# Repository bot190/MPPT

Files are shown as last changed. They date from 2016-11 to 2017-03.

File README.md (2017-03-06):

# MPPT
Maximum Power Point Tracker (MPPT)

Oh look an MQP.

Software: Use CCS: [Download TI CCS](https://www.ti.com/licreg/docs/swlicexportcontrol.tsp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) or on Hutt, or any lab computer.

This is a copy of the git repository used during the course of the project.  Contents are organized by folder and should be fairly self-explanatory.  

Board_Design contains all of the schematics and layout diagrams used for the design of the PCB. These will require NI Multisim 13 and/or NI Ultiboard 13 or later to open.

MATLAB contains matlab code used for the project, mostly for the simulation of software algorithms.  MATLAB 2015b or later should be sufficient.

PSpice contains the SPICE simulations of the circuits. These simulations were run with OrCad PSpice, but can in theory run in any SPICE netlist simulator.

Software is a TI Code Composer Studio workspace.  It includes the "Sweep" algorithm, the "Perturb and Observe" algorithm, and the "Beta" algorithm.

Any Python code was made in Python 3.

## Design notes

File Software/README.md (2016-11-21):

# Timer A0 Interrupt (4KHz)
    Configure ADC for first input
    Start ADC
    
# ADC Interrupt
    IF (Vout){
    	Add measurement to sample array
        Config ADC for V-MPPT
		Start ADC
        Enable flag to Adjust Dout
    } else if (V-MPPT) {
    	Add measurement to sample array
    	Config ADC for I-MPPT
       	Start ADC
    } else if (I-MPPT) {
    	Add measurement to sample array
       	Enable flag to Run MPPT Algorithm
       	Increment sample counter
       		Roll over at Sample Size
    }
    
If MPPT Buck doesn't see voltage when duty cycle is increased, then probably no input.
Shut off Output buck AND shut off MPPT buck. Periodically test this, turning
MPPT buck on, and leaving out buck off 
    
# Dout Adjust
    // Monitor Vout and adjust Dout as necessary
    Calulate error (setpoint - value)
    Integrate error (integrator += Ki * error)

# MPPT Algorithms

## Sweep
1. Start at 0% Duty Cycle - Ramp to 100% Duty cycle
 Calculate Power at each point update max_power_duty_cycle
2. After entire range is swept, go to max_pwer_duty_cycle

## Peturb and Observe
1. Adjust duty cycle based on perturb_dir
 Set prev_power to current_power
 Calculate current_power from current & voltage readings
2. If current_power < prev_power, reverse perturb_dir
3. Repeat forever

## Beta Method
1. Measure Voltage & Current, calculate B = ln (i/v) - C * v
2. If B is within Bmin & Bmax
 Switch to Perturb & Observe
3. Else adjust duty cycle based on B
 (Duty Cycle = D-Old + K * Bg-B)

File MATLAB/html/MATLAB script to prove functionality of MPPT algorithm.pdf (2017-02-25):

## MATLAB script to prove functionality of MPPT algorithm

Authors: Andrew Flynn, Ben Beauregard, Johnathan Adams

This script attempts to imulate the functionality of the maximum power point tracking algorithm built in C for use with the projects hardware. This is meant as a proof that the concept is sound and the algorithm will track theoretical and actual maximum power point data, not as an actual implementation to run on the hardware. As such, certain things are abstracted, such as duty cycle setting and tracking, ISRs, and other MCU-specific functionality.

Contents

Flynn's Code to load Experimental Data
Data-Error Check
Ben's MPPT Algorithm
Graph data

Flynn's Code to load Experimental Data

We're just calling another script here. It reads a data file in a terribly... unintuitive way, but it does work, and if it ain't broke...

clear;
fid = fopen('SolarSweepData.txt', 'r') ; % Open source file.
if fid == ‐1
disp('ERROR 404: File Not Found') ;
else
fgetl(fid) ; | % Read/discard line.
fgetl(fid) ; | % Read/discard line.
buffer = fread(fid, Inf) ; | % Read rest of the file.
fclose(fid);
fid = fopen('_temp.txt', 'w') ; | % Open destination file.
fwrite(fid, buffer) ; | % Save to file.
fclose(fid) ;
A = tdfread('_temp.txt') ;
delete('_temp.txt') ;
end

Data-Error Check

If we have more voltage samples than current samples something is wrong and should probably be fixed before the simulation is continued.

if length(A.Voltage_0x5BV0x5D) ~= length(A.x0x23_Current_0x5BA0x5D)
disp('Sample Size Mismatch. What are you doing?')
else
IV = [A.Voltage_0x5BV0x5D.'; A.x0x23_Current_0x5BA0x5D.'];
end

Ben's MPPT Algorithm

The "Sweep" Algorithm runs continuously in a loop using ISR's that call eachother. This shows only one complete sweep of the data, as all subsequent sweeps of identical data will give identical results.

max_power = 0; % Holds Max Power Value
max_power_ind = 0; % Emulates Duty‐Cycle tracking
power = 0; | % Holds power value for
ind = 1; | % Array Index, emulates MCU duty cycle tracking
current_sample = 0; % Current Sample Variable for readibility voltage_sample = 0; % Voltage Sample Variable for readibility

while ind < length(IV)

% Read in samples from ADC
current_sample = IV(2,ind);
voltage_sample = IV(1,ind);
power = current_sample * voltage_sample;

% If the current sample is higher than the previous maximum power % point, save it.
if power > max_power
max_power = power;
max_power_ind = ind;
end

% Increase Duty Cycle/Index ind = ind + 1;
end

Graph data

This is a wall of nonsense that I promise you works just fine and you don't have to waste your time reading.

% Here, we display consice numerical results. The wierdness comes from
% trying to stay under 80 characters per line.
disp(['The calculated maximum power was ',num2str(max_power)]);
str = 'The maximum power point was at index ';
st = ' of ';
disp([str,num2str(max_power_ind),st,num2str(length(A.Voltage_0x5BV0x5D))]); str = 'The theoretical duty cycle is ';
st = ' percent';
disp([str,num2str(100*max_power_ind/length(A.Voltage_0x5BV0x5D)),st]);

% Too complex half‐shared axis multiple y‐scale plotting
% Mostly because of MATLAB 2015... (As opposed to 2016)
x = A.Voltage_0x5BV0x5D;
y1 = A.x0x23_Current_0x5BA0x5D;
y2 = A.Voltage_0x5BV0x5D.*A.x0x23_Current_0x5BA0x5D; [hAx,hLine1,hLine2] = plotyy(x,y1,x,y2); title('Power, Current and Voltage Characteristics') xlabel('Voltage, [V]')
ylabel(hAx(1),'Current, [A]') % left y‐axis ylabel(hAx(2),'Power, [W]') % right y‐axis hLine1.LineStyle = '‐';
hLine2.LineStyle = '‐';
hold on;
v = IV(1,max_power_ind);
plot([v v], [0 max_power],'Color',[0 1 0]); grid on;
grid minor;

The calculated maximum power was 5.3695
The maximum power point was at index 30 of 36 The theoretical duty cycle is 83.3333 percent

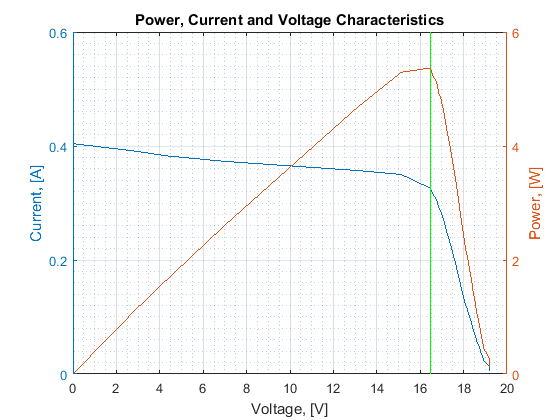
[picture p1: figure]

Published with MATLAB® R2015b (http://www.mathworks.com/products/matlab/)

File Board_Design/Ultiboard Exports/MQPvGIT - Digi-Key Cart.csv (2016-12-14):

15SQ100TR | 4
2224-H-RC | 0
2300LL-102-RC | 0
151031VS06000 | 4
1935161 | 0
ACS722LLCTR-10AU-T | 0
BZX79C3V6 | 3
DMT6009LCT | 2
ESY107M050AG3AA | 3
FB37M6K0156KC | 0
FG18C0G2A272JNT06 | 0
HDR1X2 | 4
HDR1X10 | 3
K104K10X7RF5UH5 | 2
K333K15X7RF5TH5 | 0
L78L33ABZ-AP | 0
LTI1632CN8 | 1
MIC5021YN | 1
MSP430G3553 | 2
PJ-018 | 2
RNF14FTD1K00 | 2
RNF14FTD10K0 | 2
RNF14FTD20K0 | 2
RNF14FTD75K0CT-ND | 3
RNF14FTD182R | 2
RNMF14FTC750K | 0
RSF1JT1K80 | 5

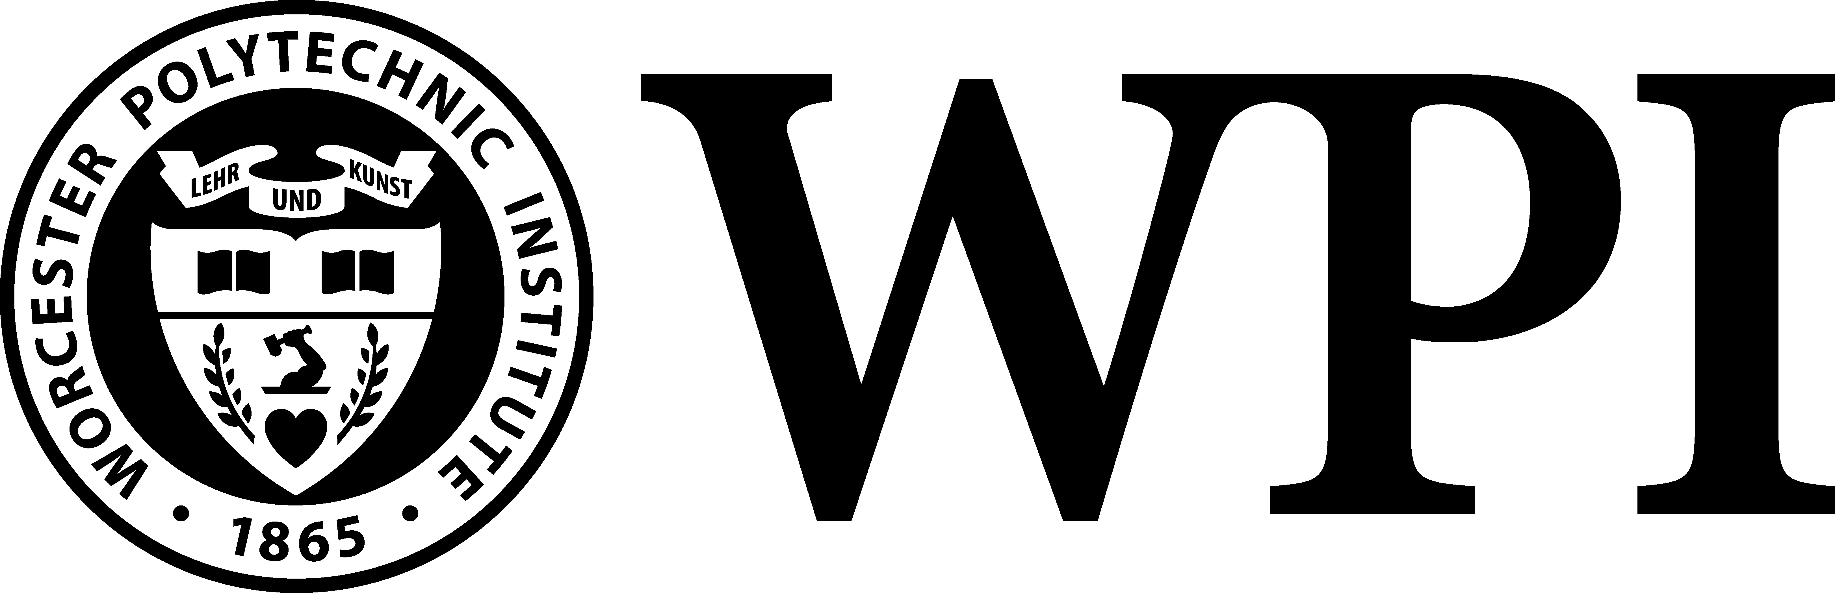
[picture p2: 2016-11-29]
Board_Design/WPI_Inst_Prim_White_Rev.bmp

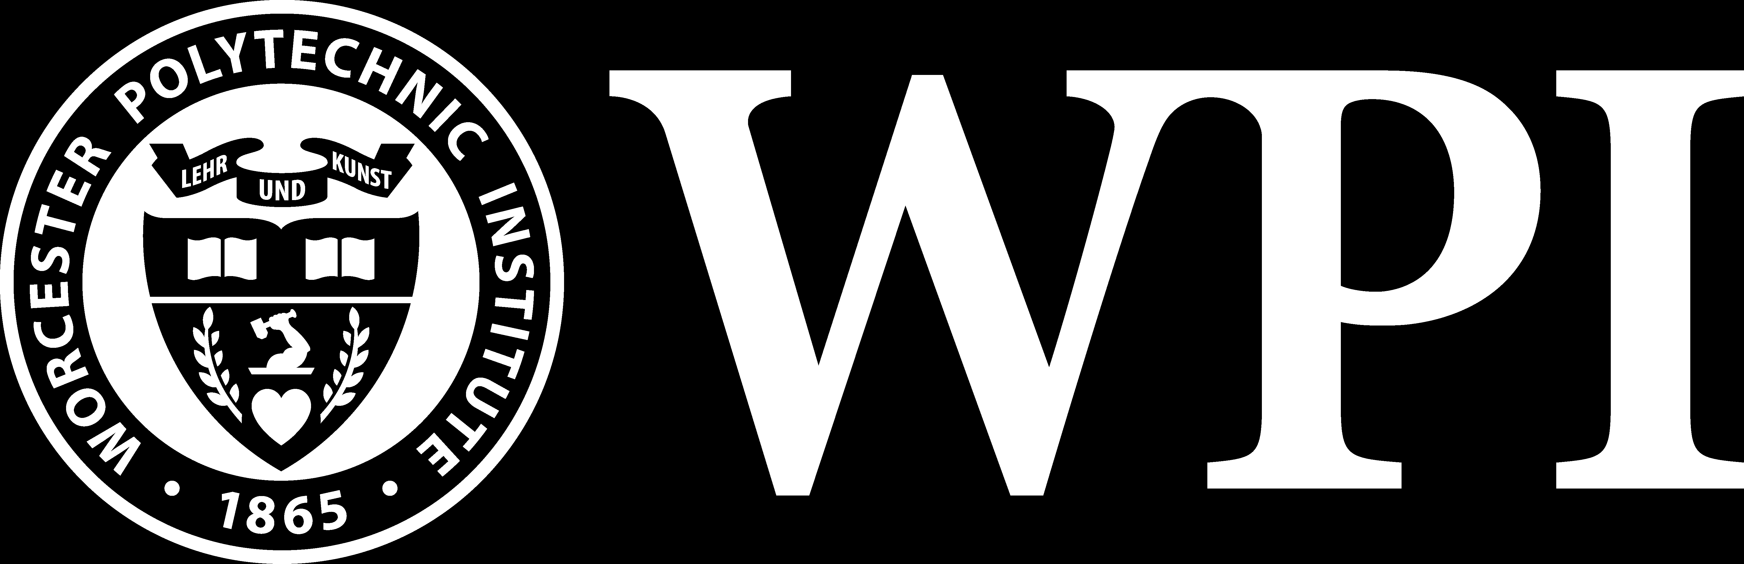
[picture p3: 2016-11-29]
Board_Design/WPI_Inst_Prim_White_Rev_Inv.bmp

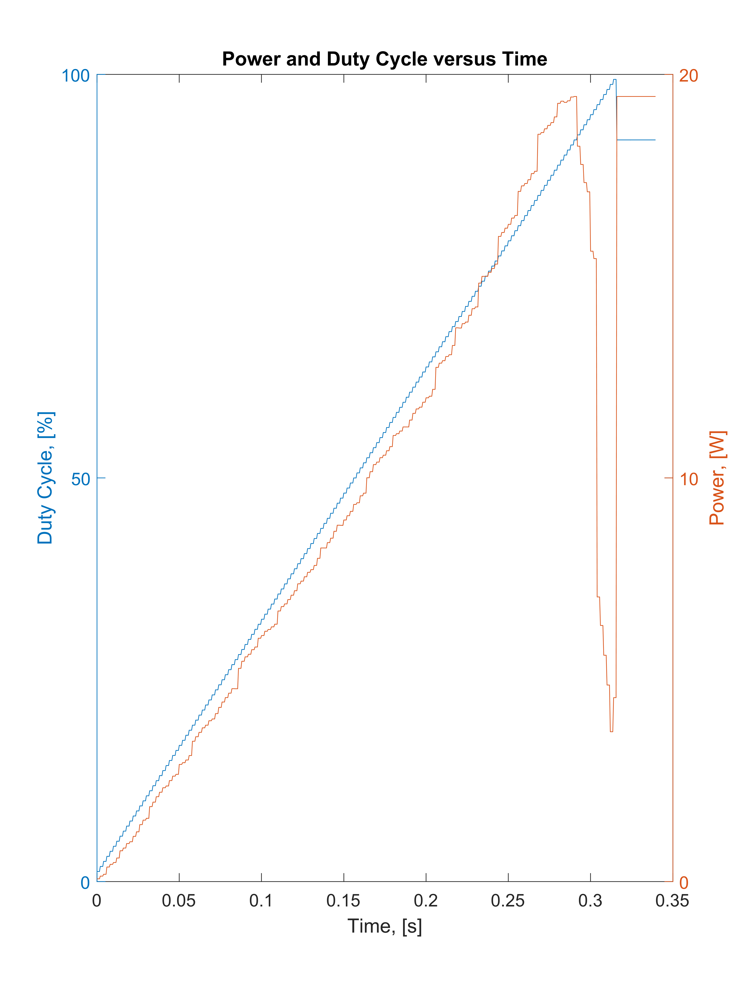
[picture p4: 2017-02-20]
MATLAB/sweep_simulation.png

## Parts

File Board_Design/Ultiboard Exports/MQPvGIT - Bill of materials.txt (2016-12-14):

Ultiboard Information Export File

Design Name  : MQPvGIT - Bill of materials
Report Date  : 8 December 2016
Report Time  : 13:30
--------------------------------------------------------------------------------

VALUE        SHAPE        #    REFDES       

15SQ100TR    R6 - SMC     4    D1,D2,D3,D4  
2224-H-RC    2224-H-RC    6    L2,L3,L4,L5,L6,L7
2300LL-102-RC 2300LL-102-RC 2    L1,L8        
151031VS06000 151031VS06000 3    LED1,LED2,LED3
1935161      1935161      3    J1,J5,J9     
ACS722LLCTR-10AU-T SOIC127P600X175-8N 1    U1           
BZX79C3V6    DO-35        2    D5,D6        
DMT6009LCT   to220        2    Q1,Q2        
ESY107M050AG3AA ESY107M050AG3AA 2    C7,C17       
FB37M6K0156KC FB37M6K0156KC 2    C1,C16       
FG18C0G2A272JNT06 FG18C0G2A272JNT06 2    C6,C12       
HDR1X2       HDR1X2       6    J2,J3,J4,J7,J8,J12
HDR1X10      HDR1X10      2    J10,J11      
K104K10X7RF5UH5 K104K10X7RF5UH5 10   C2,C3,C4,C5,C8,C9,C11,C13,C14,C18
K333K15X7RF5TH5 K104K10X7RF5UH5 2    C10,C15      
L78L33ABZ-AP TO265P419X482X935-3P 1    U3           
LT1632CN8    DIP8300      1    U6           
MIC5021YN    DIP8300      2    U2,U4        
MSP430G3553  dip20300     1    U5           
PJ-018       PJ-018       1    J6           
RNF14FTD1K00 RNF14FTD1K00 1    R1           
RNF14FTD10K0 RNF14FTD182R 1    R11          
RNF14FTD20K0 RNF14FTD182R 1    R12          
RNF14FTD75K0CT-ND RNF14FTD182R 2    R8,R10       
RNF14FTD182R RNF14FTD182R 1    R6           
RNMF14FTC750K RES1300-700X250 2    R7,R9        
RSF1JT1K80   HHV1WSJT-73-2M 4    R2,R3,R4,R5

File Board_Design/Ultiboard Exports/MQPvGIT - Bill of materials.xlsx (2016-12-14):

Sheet: MQPvGIT - Bill of materials
Ultiboard Information Export File
Design Name : MQPvGIT - Bill of materials
Report Date : 8 December 2016
Report Time : 13:30
--------------------------------------------------------------------------------
VALUE | SHAPE | # | REFDES | Have: | Need:
15SQ100TR | R6 - SMC | 4 | D1,D2,D3,D4 | 1 | 4
2224-H-RC | 2224-H-RC | 6 | L2,L3,L4,L5,L6,L7 | 8 | 0
2300LL-102-RC | 2300LL-102-RC | 2 | L1,L8 | 3 | 0
151031VS06000 | 151031VS06000 | 3 | LED1,LED2,LED3 | 0 | 4
1935161 | 1935161 | 3 | J1,J5,J9 | 3 | 0
ACS722LLCTR-10AU-T | SOIC127P600X175-8N | 1 | U1 | 2 | 0 | "Should be"
BZX79C3V6 | DO-35 | 2 | D5,D6 | 0 | 3
DMT6009LCT | to220 | 2 | Q1,Q2 | 1 | 2
ESY107M050AG3AA | ESY107M050AG3AA | 2 | C7,C17 | 0 | 3
FB37M6K0156KC | FB37M6K0156KC | 2 | C1,C16 | 3 | 0
FG18C0G2A272JNT06 | FG18C0G2A272JNT06 | 2 | C6,C12 | 4 | 0
HDR1X2 | HDR1X2 | 6 | J2,J3,J4,J7,J8,J12 | 3 | 4
HDR1X10 | HDR1X10 | 2 | J10,J11 | 0 | 3
K104K10X7RF5UH5 | K104K10X7RF5UH5 | 10 | C2,C3,C4,C5,C8,C9,C11,C13,C14,C18 | 9 | 2
K333K15X7RF5TH5 | K104K10X7RF5UH5 | 2 | C10,C15 | 3 | 0
L78L33ABZ-AP | TO265P419X482X935-3P | 1 | U3 | 3 | 0
LTI1632CN8 | DIP8300 | 1 | U6 | 1 | 1
MIC5021YN | DIP8300 | 2 | U2,U4 | 2 | 1
MSP430G3553 | dip20300 | 1 | U5 | 0 | 2
PJ-018 | PJ-018 | 1 | J6 | 0 | 2
RNF14FTD1K00 | RNF14FTD1K00 | 1 | R1 | 0 | 2
RNF14FTD10K0 | RNF14FTD182R | 1 | R11 | 0 | 2
RNF14FTD20K0 | RNF14FTD182R | 1 | R12 | 0 | 2
RNF14FTD75K0CT-ND | RNF14FTD182R | 2 | R8,R10 | 0 | 3
RNF14FTD182R | RNF14FTD182R | 1 | R6 | 0 | 2
RNMF14FTC750K | RES1300-700X250 | 2 | R7,R9 | 3 | 0
RSF1JT1K80 | HHV1WSJT-73-2M | 4 | R2,R3,R4,R5 | 0 | 5

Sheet: Shopping Cart
15SQ100TR | 4
2224-H-RC | 0
2300LL-102-RC | 0
151031VS06000 | 4
1935161 | 0
ACS722LLCTR-10AU-T | 0
BZX79C3V6 | 3
DMT6009LCT | 2
ESY107M050AG3AA | 3
FB37M6K0156KC | 0
FG18C0G2A272JNT06 | 0
HDR1X2 | 4
HDR1X10 | 3
K104K10X7RF5UH5 | 2
K333K15X7RF5TH5 | 0
L78L33ABZ-AP | 0
LTI1632CN8 | 1
MIC5021YN | 1
MSP430G3553 | 2
PJ-018 | 2
RNF14FTD1K00 | 2
RNF14FTD10K0 | 2
RNF14FTD20K0 | 2
RNF14FTD75K0CT-ND | 3
RNF14FTD182R | 2
RNMF14FTC750K | 0
RSF1JT1K80 | 5

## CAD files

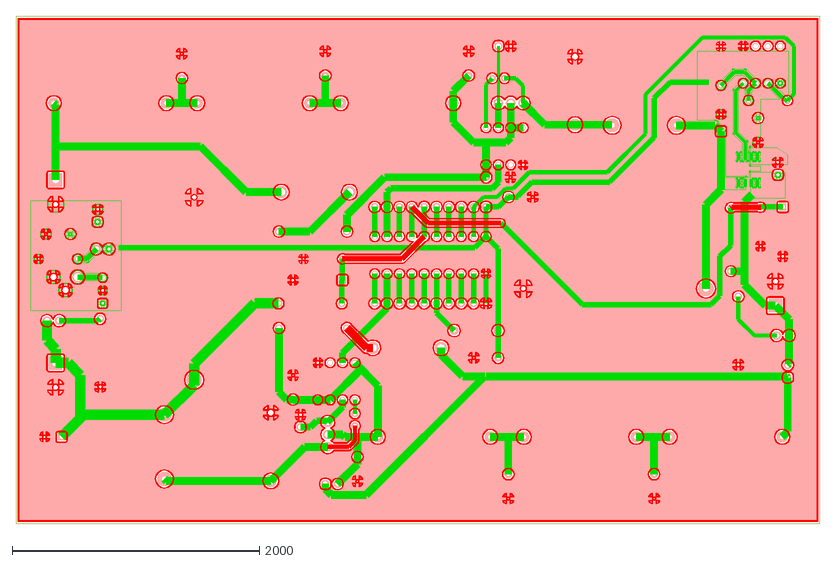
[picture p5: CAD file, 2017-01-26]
Board_Design/Ultiboard Exports/MQPvGIT.dxf
6500.0 x 4100.0

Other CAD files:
Board_Design/Solidworks/top_copper.SLDDRW

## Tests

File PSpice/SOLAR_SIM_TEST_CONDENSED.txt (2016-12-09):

   3.000E+01   1.496E-07   1.496E-01 ****     CURRENT STEP                     RMOD R =    1     
   3.000E+01   1.493E-01   1.493E-01 ****     CURRENT STEP                     RMOD R =    2     
   3.000E+01   2.980E-01   1.490E-01 ****     CURRENT STEP                     RMOD R =    3     
   3.000E+01   4.462E-01   1.487E-01 ****     CURRENT STEP                     RMOD R =    4     
   3.000E+01   5.939E-01   1.485E-01 ****     CURRENT STEP                     RMOD R =    5     
   3.000E+01   7.411E-01   1.482E-01 ****     CURRENT STEP                     RMOD R =    6     
   3.000E+01   8.877E-01   1.479E-01 ****     CURRENT STEP                     RMOD R =    7     
   3.000E+01   1.034E+00   1.477E-01 ****     CURRENT STEP                     RMOD R =    8     
   3.000E+01   1.179E+00   1.474E-01 ****     CURRENT STEP                     RMOD R =    9     
   3.000E+01   1.324E+00   1.472E-01 ****     CURRENT STEP                     RMOD R =   10    
   3.000E+01   1.469E+00   1.469E-01 ****     CURRENT STEP                     RMOD R =   11    
   3.000E+01   1.613E+00   1.466E-01 ****     CURRENT STEP                     RMOD R =   12    
   3.000E+01   1.756E+00   1.464E-01 ****     CURRENT STEP                     RMOD R =   13    
   3.000E+01   1.899E+00   1.461E-01 ****     CURRENT STEP                     RMOD R =   14    
   3.000E+01   2.042E+00   1.458E-01 ****     CURRENT STEP                     RMOD R =   15    
   3.000E+01   2.184E+00   1.456E-01 ****     CURRENT STEP                     RMOD R =   16    
   3.000E+01   2.325E+00   1.453E-01 ****     CURRENT STEP                     RMOD R =   17    
   3.000E+01   2.466E+00   1.451E-01 ****     CURRENT STEP                     RMOD R =   18    
   3.000E+01   2.607E+00   1.448E-01 ****     CURRENT STEP                     RMOD R =   19    
   3.000E+01   2.747E+00   1.446E-01

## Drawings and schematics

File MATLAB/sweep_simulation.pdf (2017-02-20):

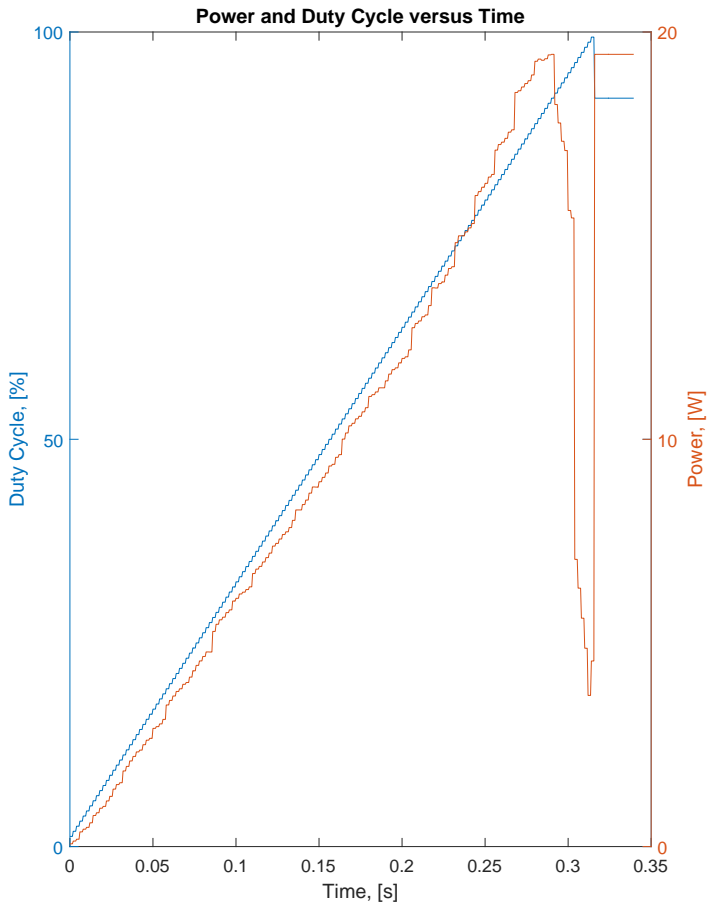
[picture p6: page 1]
Time, [s]; Duty Cycle, [%]; Power, [W]

Power and Duty Cycle versus Time

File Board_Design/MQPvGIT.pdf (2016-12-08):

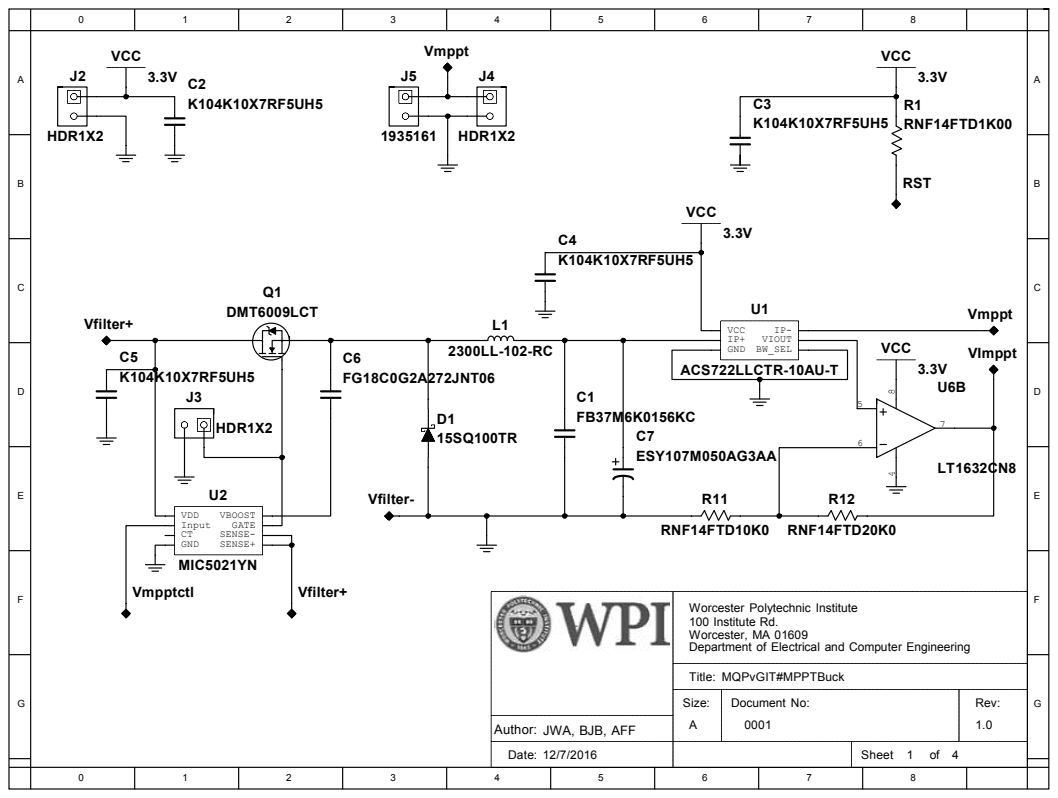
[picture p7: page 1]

Worcester Polytechnic Institute
100 Institute Rd.
Worcester, MA 01609
Department of Electrical and Computer Engineering

Author: JWA, BJB, AFF

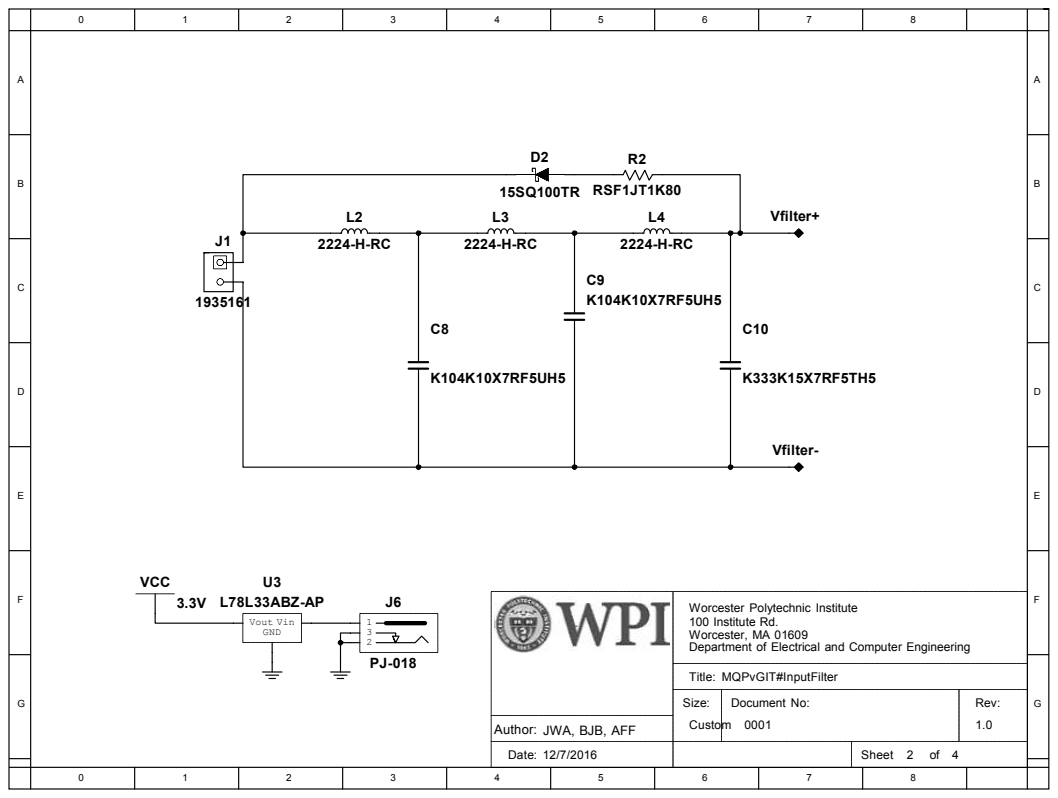
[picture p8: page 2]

Worcester Polytechnic Institute
100 Institute Rd.
Worcester, MA 01609
Department of Electrical and Computer Engineering

Author: JWA, BJB, AFF

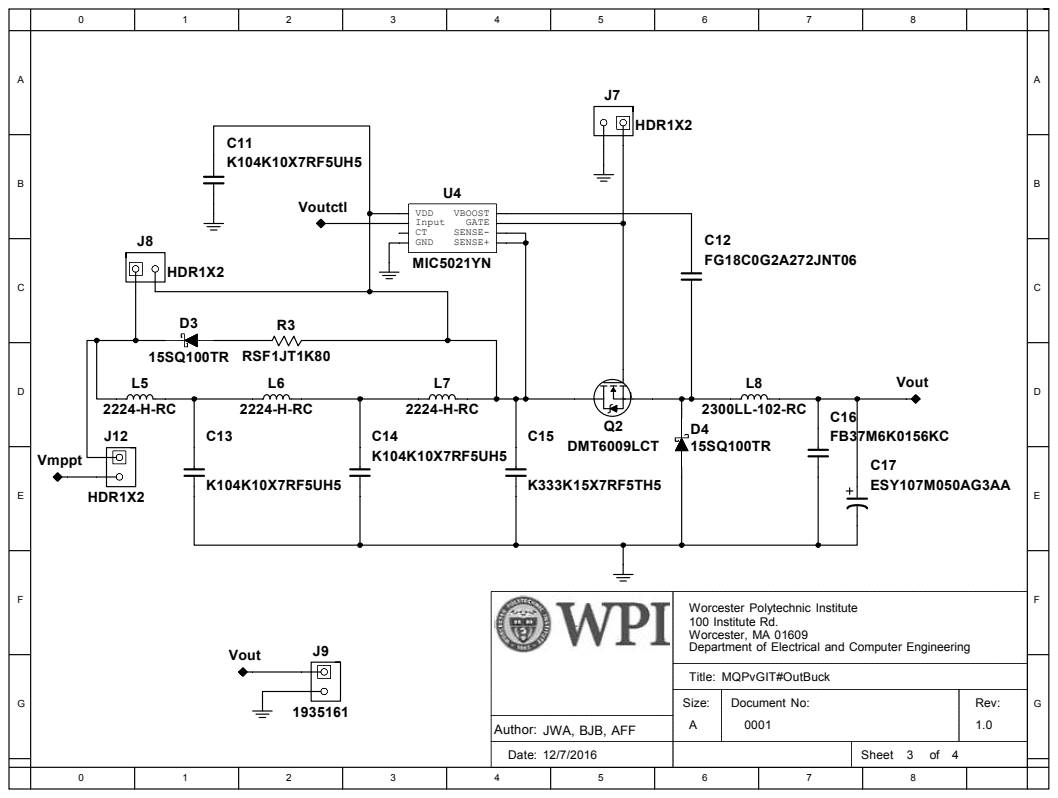
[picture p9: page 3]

Worcester Polytechnic Institute
100 Institute Rd.
Worcester, MA 01609
Department of Electrical and Computer Engineering

Author: JWA, BJB, AFF

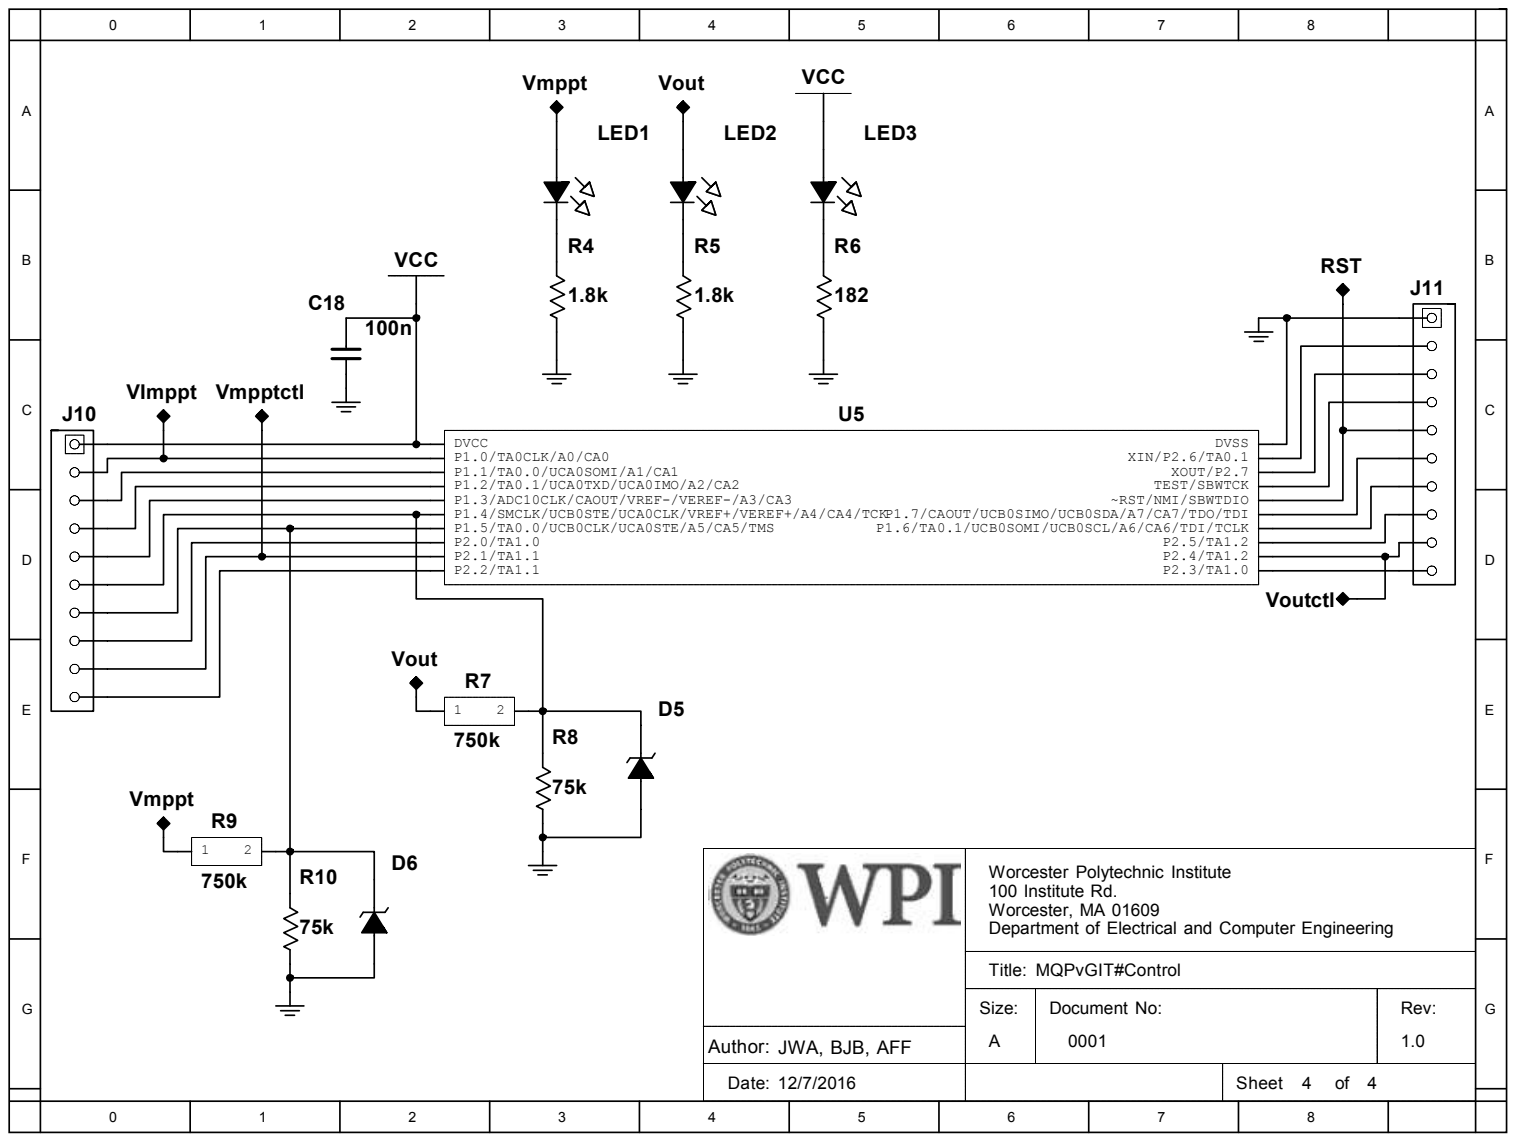
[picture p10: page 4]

Worcester Polytechnic Institute
100 Institute Rd.
Worcester, MA 01609
Department of Electrical and Computer Engineering

Author: JWA, BJB, AFF

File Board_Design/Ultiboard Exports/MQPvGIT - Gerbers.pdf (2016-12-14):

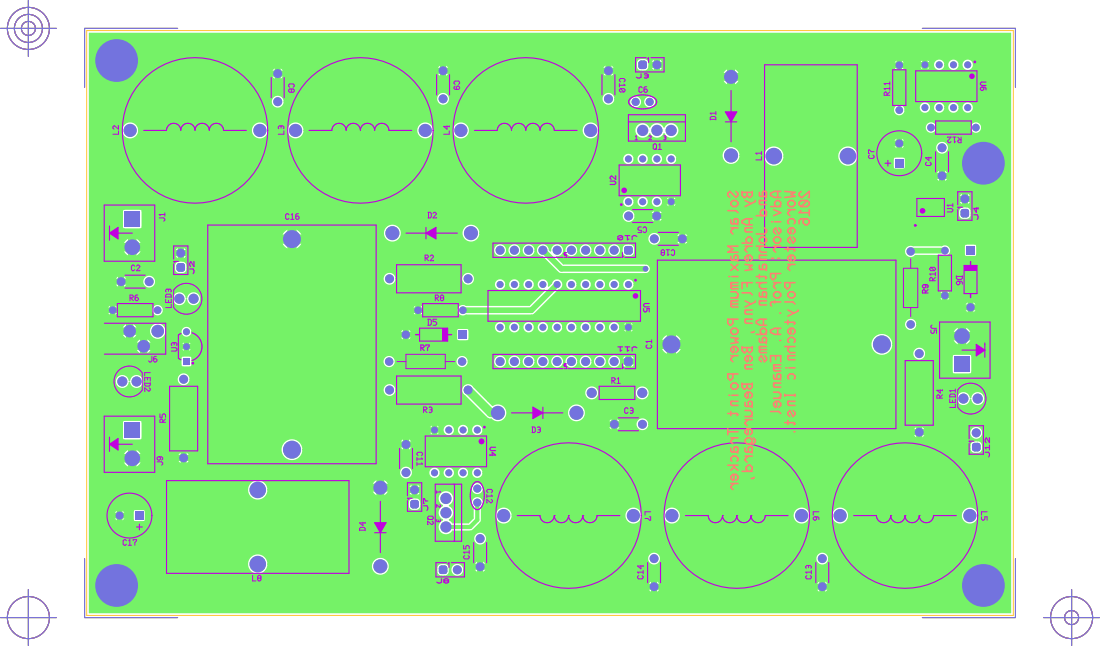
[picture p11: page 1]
Evaluation

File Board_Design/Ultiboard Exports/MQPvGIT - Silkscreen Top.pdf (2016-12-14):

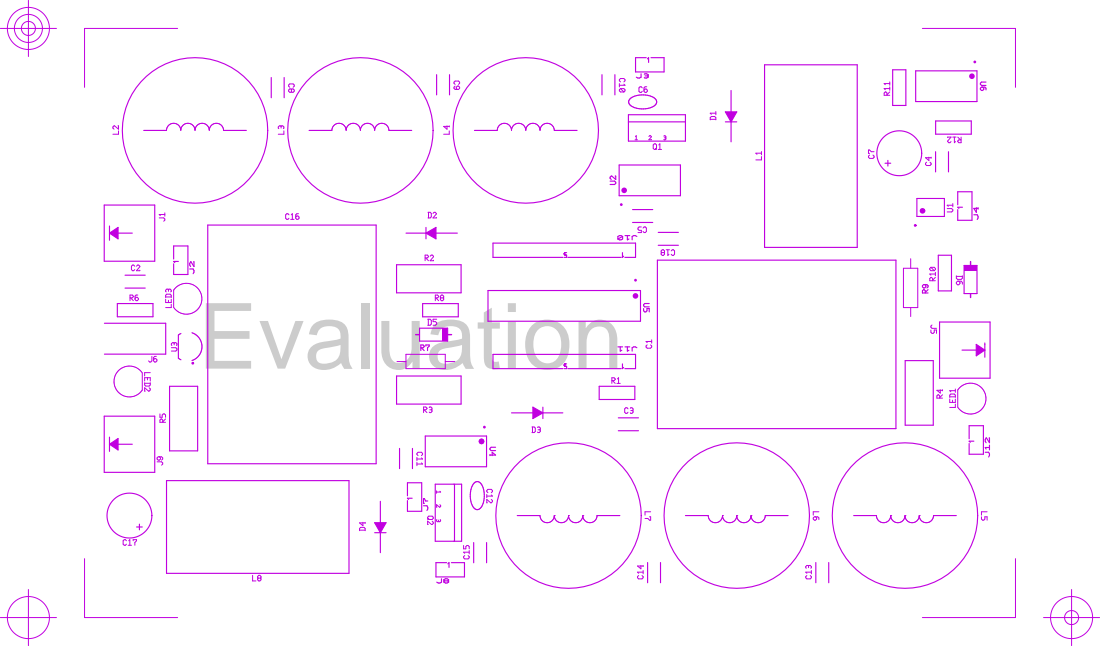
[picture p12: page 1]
Evaluation

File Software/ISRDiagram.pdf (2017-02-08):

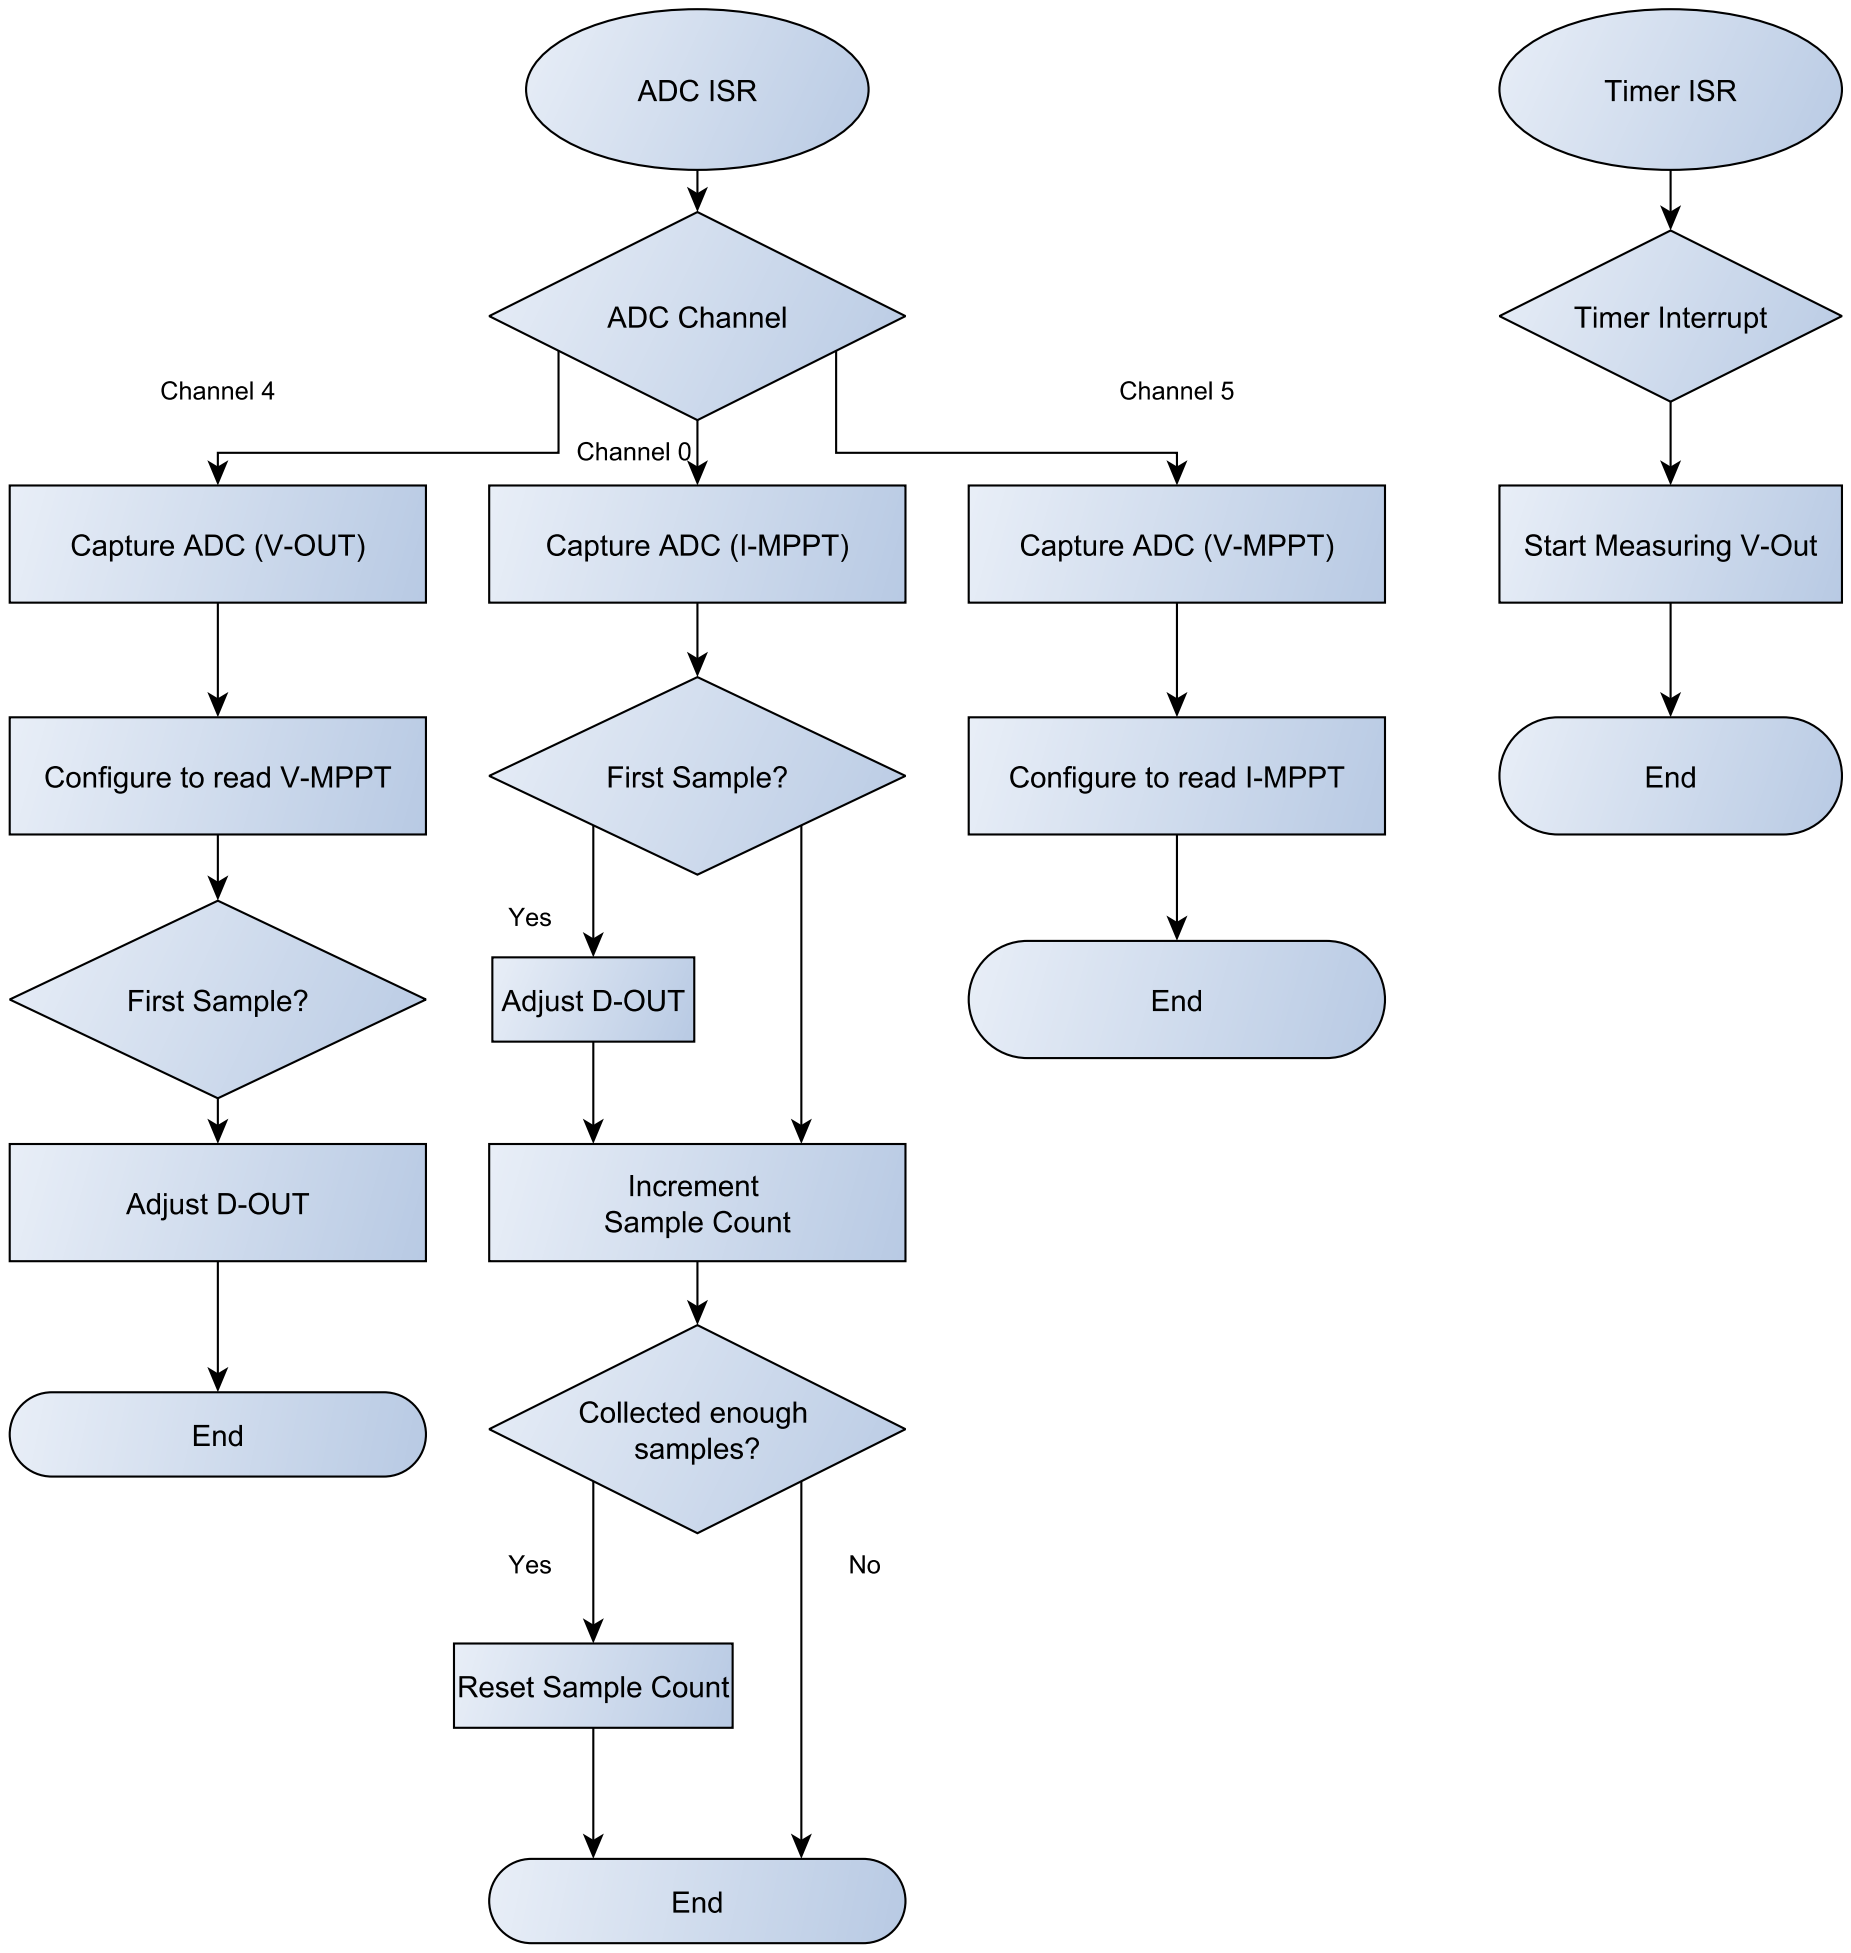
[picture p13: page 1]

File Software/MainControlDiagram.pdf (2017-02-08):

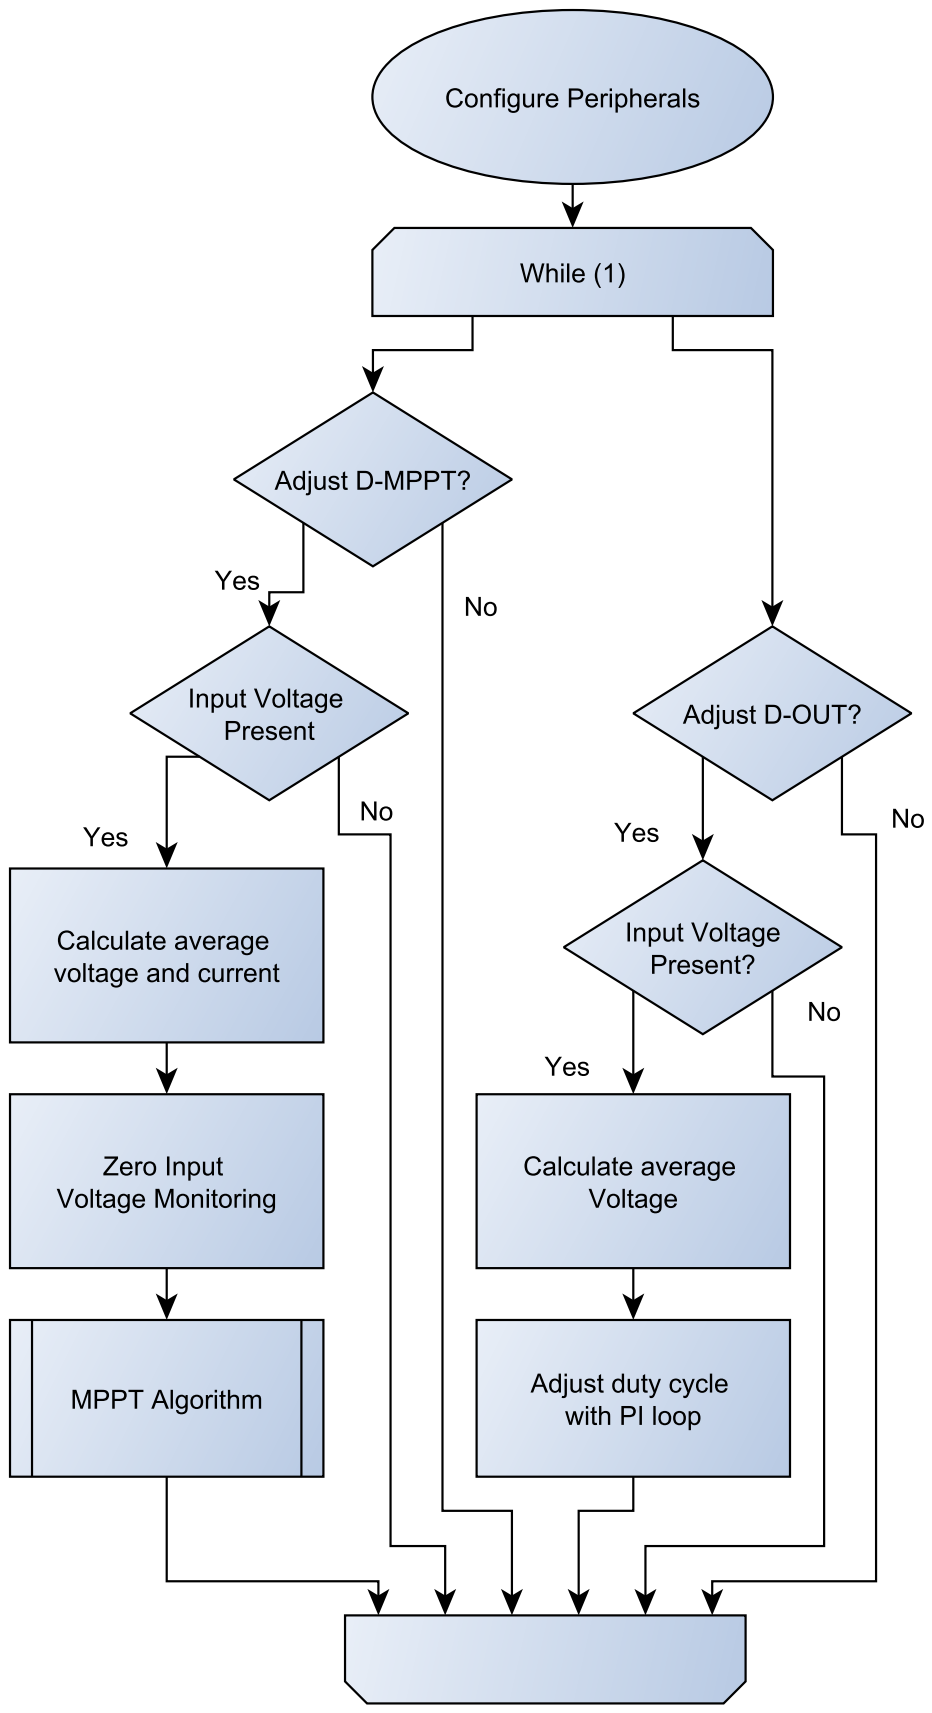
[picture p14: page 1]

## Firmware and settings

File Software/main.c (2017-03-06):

/******************************************************************************
 *                    Maximum Power Point Tracker (MPPT)
 *
 * This code implements multiple algorithms for finding and tracking the
 * maximum power point of a solar panel.
 *
 * This project is in fulfillment of the Major Qualifying Project at
 * Worcester Polytechnic Institute.
 *
 * Authored by:
 * 	Johnathan Adams
 * 	Ben Beauregard
 * 	Andrew Flynn
 *
 *****************************************************************************/
// Includes
#include <msp430.h>
#include <limits.h>
#include "main.h"
#include "sweep.h"
//#include "beta.h"
#include "perturbobserve.h"

/* Define Global Variables */
// Store V-OUT from ADC
unsigned int v_out;
// Store V-OUT samples
int v_out_samples[AVERAGE_LENGTH];
// Saturation-Flag for integral computation (part of PID)
signed char v_out_sat;
// Value of Vout integral computation
long v_out_integral;
// Integration "parameter" (constant, multiplies error in integral calculation)
const int v_out_i = 1024;
// Store V-MPPT average from ADC
unsigned int v_mppt;
// Store V-MPPT samples
int v_mppt_samples[AVERAGE_LENGTH];
// Store I-MPPT average from ADC
unsigned int i_mppt;
// Store I-MPPT samples
int i_mppt_samples[AVERAGE_LENGTH];

// Proportional Constant = 1/2^Divisor
const int Divisor = 3;
// Counts the number of samples used for any average computation
unsigned int sample;
// Cycle counter for handling 0V input condition
unsigned char zero_samples;
// MPPT Duty Cycle - Start at 25%
int mppt_duty_cycle=80;

//Bitmask (see header).
volatile char DCTL;
// BITMASK of Buttons being pressed
volatile char BUTTONS;

// Calculated power draw from MPPT Buck Converter
unsigned long power;

// Define algorithm variable to choose MPPT algorithm
enum mppt_algorithm_type_enum algorithm = MPPT_SWEEP;

// State variable for MPPT state machine
enum mppt_states_enum mppt_state = MPPT_WAIT;
// State variable for VOUT state machine
enum vout_states_enum vout_state = VOUT_WAIT;

void main(void) {

    // Stop watchdog timer
    WDTCTL = WDTPW | WDTHOLD;
    /*
     * Configure Clocks
     */
    // 16MHz calibrated clock
    DCOCTL = CALDCO_16MHZ;
    // Set ACLK to /2
    BCSCTL1 = (CALBC1_16MHZ);
    // MCLK & SMCLK from DCO, both divided by 1, DCO resistor internal
    BCSCTL2 = 0b00000000;
    // Use VLOCLK for ACLK
    BCSCTL3 = LFXT1S_2;

    /*  PIN MAP
     * P1.0 - I - I-MPPT - A0
     * P1.1 - I - Algorithm Reset Button
     * P1.2 - I - Algorithm Change Button
     * P1.3 - O - UNUSED
     * P1.4 - I - V-OUT - A4
     * P1.5 - I - V-MPPT - A5
     * P1.6 - O - UNUSED
     * P1.7 - O - UNUSED
     * P2.0 - O - UNUSED
     * P2.1 - O - Gate Driver MPPT MOSFET - TA1.1
     * P2.2 - O - UNUSED
     * P2.3 - O - UNUSED
     * P2.4 - O - Gate Drive V-OUT MOSFET - TA1.2
     * P2.5 - O - UNUSED
     * P2.6 - O - UNUSED
     * P2.7 - O - UNUSED
     */

    /*
     * Configure GPIO
     */
    // Set P2.1 and P2.4 to output direction
    P2DIR = (BIT1 | BIT4);
    // Set P2.1 and P2.4 to primary function
    P2SEL = (BIT1 | BIT4);
    /*
     * Configure unused pins
     */
    // Set unused P1 pins to output
    P1DIR = (BIT3 | BIT6 | BIT7);
    // Enable pull-up resistor for P1.1
    P1REN = (BIT1 | BIT2);
    // Setting BIT1 uses the Pull-Up resistor instead of the pull down resistor
    P1OUT = (BIT1 | BIT2 | BIT3 | BIT7);
    // Set unused P2 pins to output
    P2DIR |= (BIT0 | BIT2 | BIT3 | BIT5 | BIT6 | BIT7);
    // Set all P3 pins to output
    P3DIR = 0xF;
    P3OUT = 0x0;
    P3REN = 0xF;

    /*
     * Configure ADC - Run on MCLK - 16MHz/4 = 4MHzx64 = 16uS
     */
    // Use Vcc and Vss, S&H Time: 64*ADC10CLKs, turn on ADC, enable interrupt
    ADC10CTL0 = (SREF_0 | ADC10SHT_3 | ADC10ON | ADC10SR | ADC10IE);
    // Use MCLK/4
    ADC10CTL1 = (ADC10SSEL_2 | ADC10DIV_3);
    // Using A0, A4, and A5
    ADC10AE0 = (BIT0 | BIT4 | BIT5);
    // Not using the DTC

    /*
     * Configure Timer1 - SMCLK
     * PWM at 50KHz with 16MHz Clock
     * Count to 320-1
     */
    // Use SMCLK, /1 divider, Up mode
    TA1CTL = (TASSEL_2 | ID_0 | MC_1);
    // Compare 1 should reset/set TA1.1
    TA1CCTL1 = OUTMOD_7;
    // Compare 2 should reset/set TA1.2
    TA1CCTL2 = OUTMOD_7;
    // PWM frequency should be 50KHz
    TA1CCR0 = (MAX_DUTY_CYCLE - 1);

    /*
     * Configure Timer0 - ACLK
     */
    // Use ACLK, /1 divider, Up mode
    TA0CTL = (TASSEL_1 | ID_0 | MC_1 | TAIE);
    // 12KHz clock, into 3 gives 4KHz
    TA0CCR0 = (LOW_FQ_CLOCK);

    //Global Interrupt Enable
    _BIS_SR(GIE);

    // Iterator variable because this isn't c99 apparently
    unsigned int i;

    // Code Body
    while (1) {
        switch (mppt_state) {
            case MPPT_WAIT:
                if (DCTL & MPPT_CONTROL) {
                    // Mark that we've moved on
                    DCTL &= ~MPPT_CONTROL;
                    // If we have fresh data, move on to limit run speed
                    mppt_state = MPPT_LIMIT_SPEED;
                }
                break;
            case MPPT_LIMIT_SPEED:
                // Desired Frequency / (12KHz / TA0CCR0 / 8)
                if (slow_down >= MPPT_LIMITER) {
                    slow_down = 0;
                    // Call button handler
                    button_handler();
                    // Check for low voltage
                    mppt_state = MPPT_LOW_VOLT_HANDLER;
                } else {
                    slow_down++;
                    mppt_state = MPPT_WAIT;
                }
                break;
            case MPPT_LOW_VOLT_HANDLER:
                if (DCTL & INPUT_VOLTAGE_PRESENT) {
                    // Calculate new data before Low Volt check
                    mppt_state = MPPT_AVERAGE;
                } else {
                    // Handle Low Volt flag
                    mppt_state = MPPT_LOW_VOLT_DETECTED;
                }
                break;
            case MPPT_LOW_VOLT_DETECTION:
                // Check if voltage is low before proceeding
                if (v_mppt < (V_MARGIN)) {
                    if (zero_samples >= 20) {
                        zero_samples = 0;
                        // Not detecting a voltage, lets wait for the next run
                        DCTL &= ~INPUT_VOLTAGE_PRESENT;
                        mppt_state = MPPT_WAIT;
                        break;
                    } else {
                        zero_samples++;
                    }
                }
                // Voltage is still good, run algorithm
                mppt_state = MPPT_ALGORITHM;
                break;
            case MPPT_LOW_VOLT_DETECTED:
                zero_samples++;
                if (zero_samples >= 20) {
                    DCTL |= INPUT_VOLTAGE_PRESENT;
                    // Zero integrals to avoid unnecessarily integrated error
                    v_out_integral = 0;
                    zero_samples = 0;
                    // Call MPPT algorithm check for output voltage
                    mppt_state = MPPT_AVERAGE;
                    break;
                }
                mppt_state = MPPT_WAIT;
                break;
            case MPPT_AVERAGE:
                // Get average current and voltage
                i_mppt = v_mppt = 0;
                for (i = AVERAGE_LENGTH; i > 0; i--) {
                    // Calculate average I-MPPT
                    i_mppt += i_mppt_samples[i - 1];
                    // Calculate average V-MPPT
                    v_mppt += v_mppt_samples[i - 1];
                }
                i_mppt = i_mppt >> AVERAGE_LENGTH_BIT;
                v_mppt = v_mppt >> AVERAGE_LENGTH_BIT;
                // Now that we have samples, check if voltage present
                mppt_state = MPPT_LOW_VOLT_DETECTION;
                break;
            case MPPT_ALGORITHM:
                // Run MPPT algorithm (Set duty cycle - TA1CCR1)
                call_algorithm();
                mppt_state = MPPT_WAIT;
                break;
            default:
                break;
        }

        switch (vout_state) {
            case VOUT_WAIT:
                // Sit until we've collected new data
                if (DCTL & VOUT_CONTROL) {
                    vout_state = VOUT_LOW_VOLT_HANDLER;
                }
                break;
            case VOUT_LOW_VOLT_HANDLER:
                if (DCTL & INPUT_VOLTAGE_PRESENT) {
                    vout_state = VOUT_AVERAGE;
                } else {
                    vout_state = VOUT_DISABLE;
                }
                break;
            case VOUT_AVERAGE:
                v_out = 0;
                for (i = AVERAGE_LENGTH; i > 0; i--) {
                    v_out += v_out_samples[i - 1];
                }
                v_out = v_out >> AVERAGE_LENGTH_BIT;
                // Call control algorithm after computing average of samples
                vout_state = VOUT_ALGORITHM;
            case VOUT_ALGORITHM:
                // Run Vout Control algorithm
                TA1CCR2 += adjust_output_duty_cycle(v_out, V_SETPOINT,
                        &v_out_sat, &v_out_integral, v_out_i, Divisor);
                if (TA1CCR2 >= MAX_DUTY_CYCLE) {
                    TA1CCR2 = MAX_DUTY_CYCLE;
                }
                break;
            case VOUT_DISABLE:
                TA1CCR2 = 0;
                vout_state = VOUT_WAIT;
                break;
        }
    }
}

/** \brief Timer A0 ISR that starts ADC measurements
 *
 * Function starts ADC CH2 (V-OUT) measurement when TA0 rolls over.
 * The period is controlled by TA0CCR0
 */
#pragma vector=TIMER0_A1_VECTOR
__interrupt void timerA0_ISR(void) {
    if (TA0IV == 0xA) {
        // TACCR1
        // Read	A4 / V-OUT
        ADC10CTL0 &= ~ENC;
        ADC10CTL1 &= 0xFFF;
        ADC10CTL1 |= INCH_4;
        // Start ADC conversion
        ADC10CTL0 |= (ENC | ADC10SC);
        periodic_timer_count++;
    }
}

/** \brief ADC10 ISR stores measurement, and kicks-off next one if necessary.
 *
 * Function copies measurement value into the respective global variable.
 * Kicks off V-MPPT measurement, then I-MPPT measurement. Also calls
 * adjust_out_duty_cycle to control D-OUT.
 */
#pragma vector=ADC10_VECTOR
__interrupt void ADC10_ISR(void) {
    switch (ADC10CTL1 >> 12) {
        // I-MPPT
        case (0x0):
            i_mppt_samples[sample] = ADC10MEM;
            // Only update Duty cycle at 500Hz
            // Increment sample count, roll over at 3
            sample++;
            if (sample == AVERAGE_LENGTH) {
                sample = 0;
                DCTL |= MPPT_CONTROL;
            }
            break;
        // V-MPPT
        case (0x5):
            v_mppt_samples[sample] = ADC10MEM;
            // Read	A0 / I-MPPT
            ADC10CTL0 &= ~ENC;
            ADC10CTL1 &= 0xFFF;
            ADC10CTL1 |= INCH_0;
            // Start ADC conversion
            ADC10CTL0 |= (ENC | ADC10SC);
            break;
        // V-OUT
        case (0x4):
            v_out_samples[sample] = ADC10MEM;
            // Read	A5 / V-MPPT
            ADC10CTL0 &= ~ENC;
            ADC10CTL1 &= 0xFFF;
            ADC10CTL1 |= INCH_5;
            // Start ADC conversion
            ADC10CTL0 |= (ENC | ADC10SC);
            // Enable D-OUT algorithm at 500Hz
            if (sample == 0) {
                DCTL |= VOUT_CONTROL;
            }
            break;
    }
}

/** \brief Adjusts the Duty Cycle of output buck converter
 *
 * Function adjusts the Duty Cycle of the output buck converter based on the
 * measured voltage and the set-point. Uses a proportional algorithm to adjust
 * duty cycle.
 */
int adjust_output_duty_cycle(int input, int setpoint, signed char *sat,
        long *x_integral, int Ki2, int n) {
    int e = setpoint - input;
    int x;

    /* If there isn't saturation, or there is,
     * but saturation is the opposite direction from the error
     */
    if (! ((*sat < 0 && e < 0) || (*sat > 0 && e > 0))) {
        *x_integral = *x_integral + (long) Ki2 * e;
        // Keep integral within range
        if (*x_integral > LONG_MAX) {
            *x_integral = LONG_MAX;
            *sat = 1;
        } else if (*x_integral < LONG_MIN) {
            *x_integral = LONG_MIN;
            *sat = -1;
        } else {
            *sat = 0;
        }
        x = (e >> n) + (int) (*x_integral >> 16);
    }
    return x;
}

/** \brief Changes the current algorithm
 *
 * This function cycles through the implemented algorithms.
 */
void change_algorithm() {
    switch (algorithm) {
        case MPPT_SWEEP:
            algorithm = MPPT_PERTURBOBSERVE;
            break;
        case MPPT_PERTURBOBSERVE:
            algorithm = MPPT_SWEEP;
            break;
        case MPPT_BETA:
            break;
        default:
            break;
    }
}

/** \brief Calls algorithm reset function
 *
 * This function calls the chosen algorithm's reset function
 */
void reset_algorithm() {
    switch (algorithm) {
        case MPPT_SWEEP:
            sweep_reset(&DCTL);
            break;
        case MPPT_PERTURBOBSERVE:
            perturb_and_observe_reset();
            break;
        case MPPT_BETA:
            //beta_reset(&DCTL);
            break;
        default:
            break;
    }
}

/** \brief Calls algorithm function
 *
 * This function calls the chosen algorithm's main function
 */
void call_algorithm() {
    switch (algorithm) {
        case MPPT_SWEEP:
            TA1CCR1 = sweep(&DCTL);
            break;
        case MPPT_PERTURBOBSERVE:
            TA1CCR1 = perturb_and_observe(&DCTL);
            break;
        case MPPT_BETA:
//          TA1CCR1 = beta(&DCTL);
            break;
        default:
            break;
    }
}

/** \brief Handles debouncing buttons
 *
 * This function handles debouncing buttons and calling the appropriate
 * button handler
 */
void button_handler() {
    //Button handling
    if ((P1IN & BIT1) == 0) {
        BUTTONS |= RESET_BUTTON_PRESSED;
    } else if (BUTTONS & RESET_BUTTON_PRESSED) {
        // Button is no longer pressed
        BUTTONS &= ~RESET_BUTTON_PRESSED;
        reset_algorithm();
    }
    if ((P1IN & BIT2) == 0) {
        BUTTONS |= ALGORITHM_BUTTON_PRESSED;
    } else if (BUTTONS & ALGORITHM_BUTTON_PRESSED) {
        // Button is no longer pressed
        BUTTONS &= ~ALGORITHM_BUTTON_PRESSED;
        change_algorithm();
    }
}

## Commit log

2016-10-26 Added circuit simulation
    Added circuit simulation for full MPPT, including solar cell emulator,
    filters, MPPT buck converter and output buck converter
2016-10-27 Building a "Wrapper"
    Lauer likes to call it a wrapper, though I don't like calling it that.
    This update is about building a framework in which to put code later.
2016-10-27 Updated circuit to latest design
    Removed CMOS Gate Driver circuit in favor of simulated high side gate driver.
2016-10-27 Clock Configuration Get
    Framework further expanded, started config code by adding clock
    configuration.
2016-10-27 Updated Clock configuration to use the calibrated 16MHz value. P1.4 outputs SMCLK for debug purposes.
2016-10-27 Added freewheeling diodes across filters
    Used MBR1060 diode model, placed diode from output of filter to input of
    filter
2016-10-28 Fixed Global Interrupt Enable
    Literally added one underscore.
    [main.c]
2016-10-28 100% Critical, Necessary Changes
    Corrected the spelling of my name in a comment.
    [main.c]
2016-10-28 MCU Circuitry Updated
    Added pin headers for GPIO pins, added filter caps, added brownout protection resistor, added title blocks.
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2016-11-01 Testing in prep for PWM (hopefully)
    -temporarily removed second filter and buck converter, connected load to
    first buck
    -changed rise and fall time of PULSE and changed max step time to fix
    convergence issues and speed up simulation
    -changed VSOLAR from 36.7 to 30 to reflect real conditions
    -began experimenting with SCHEDULE to simulate ramped PWM
2016-11-02 More PWM testing
    Continuing to look into using parameters to to control pulse width
2016-11-02 Now using MSP430G2553
    The Texas Instruments MSP430 family of ultra-low-power microcontrollers
    consists of several devices featuring
    different sets of peripherals targeted for various applications. The
    architecture, combined with five low-power
    modes, is optimized to achieve extended battery life in portable
    measurement applications. The device features a
    powerful 16-bit RISC CPU, 16-bit registers, and constant generators that
    contribute to maximum code efficiency.
    The digitally controlled oscillator (DCO) allows wake-up from low-power
    modes to active mode in less than 1 µs.
    The MSP430G2x13 and MSP430G2x53 series are ultra-low-power mixed signal
    microcontrollers with built-in 16-
    bit timers,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
2016-11-03 PWM WORKS NOW
    HOLY SWEET JESUS HALLELUJAH THE PWM WORKS!!!!!
    THE PSPICE G-DS HAVE SMILED DOWN UPON US!!!
    "PWM_TRIAL_3.CIR" succesfully uses a comparator with a triangle wave and
    a step voltage source to produce a PWM output that changes with time
    (changes every 5ms)!
    The python script was used to generate the table of time and voltage
    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
2016-11-04 Added Current and Voltage measurement logic
    *Re-organized comments, moving them above the code referenced
    *Added TimerA0 ISR - Kicks off ADC Ch2 conversion
    *Added ADC10 ISR, - Kicks off ADC CH1, and CH0 conversion, calls D-Out
    management funciton
    *Configured TimerA0 and TimerA1
2016-11-04 Cleaned up circuit file
    Moved models and component sub circuits to library file, removed old
    revision notes from the olden days before Git. Next task is adding in
    PWM
2016-11-04 Started adding support for D-OUT control.
    Created README.md to outline code flow.
2016-11-08 The continuing saga of how to get PWM
    finally looking at opting towards a brute-force method by manually
    defining the waveform for the PWM. That is, 4 defined points per period.
    In order to keep this organized, we're looking at a voltage source made
    up of over 50,000 lines of code. Buckle your seatbelts and hold onto
    your hats folks... it's gonna be a derpy ride
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2016-11-09 Working to fix convergence issues
    added capacitor to gate pin of buck converter mosfet which seemed to
    help when using the comparator based PWM source. Also added a resistor
    on the input of the comparator, and did some more cleanup of unused
    portions of the PSpice code
2016-11-10 Cleaned up some bit manipulation, modified ADC channels
    Cleaned up bit level register manipulation code. Made the setpoint a
    #define, adjusted comments.
    We found that P1.1 and P1.2 are being held up to almost Vcc for some
    reason. Moving the connections to P1.4 and P1.5 to fix this.
    [main.c]
2016-11-10 Playing with buck converters
    Running a number of different simulations to address issue where the
    first buck converter output voltage is higher than expected. This is
    thought to be occuring due to a lower current draw in the first buck
    converter than in the second buck converter which is connected to the
    load Thus, the first buck converter is not fully discharging each cycle.
    This does seem to go away with a higher current, as demonstrated by
    using a low resistance load.
    Also, added 100 ohm resistors in series with the freewheeling diodes on
    the filters, per Prof. E's suggestion
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2016-11-11 Average measurements at 4KHz vs 1Hz, move Duty cycle tracking to main
    Increased measurement speed to 4KHz from 1 Hz, takes a 4 sample average
    over this time and then calls adjustment functions at 1KHz.
    Moved duty cycle adjustment to a while loop in main. The functions only
    happen when a flag is set by the ADC ISR. Still need to put the core to
    sleep between interrupts.
2016-11-15 Made a bunch of fixes to my previous attempt.
    Lots of small issues, such as out of bound indexes, not reseting
    variables correctly, general badness for calculating averages.
    Lots of stupid stuff.
    [main.c]
2016-11-15 Increased the measurement frequency back to its previous levels
    After confirming the previous fixes worked as expected, I was able to
    increase the measurement frequency back to the previous value of 4KHz.
    The duty cycle is updated at ~500Hz, or 4KHz / 8.
    [main.c]
2016-11-16 Added Power supply
    Some minor arrangement changes as well, nothing else functional changed.
2016-11-16 Removed Output filter in favor of 100uF Capacitor
    Capacitors, what do they do?
    I remember this not working in simulation, but it worked just fine in
    reality.
2016-11-16 Added an Integral component to the control loop
    Now controls voltage with a PI loop, as this allows for the voltage to
    get closer to the desired value, and helps it get there quicker.
    I also added code to detect when the input voltage is zero. After
    finding the input to be zero for a short period it stops the output. It
    then turns the buck converter on temporarily to see if there is any
    power available. This also solves an issue where the integrator would
    get quite large when it shouldn't.
    [main.c]
2016-11-17 Changed Control Block Resistors, Added BoM
    https://www.youtube.com/watch?v=dQw4w9WgXcQ
    https://www.youtube.com/watch?v=dQw4w9WgXcQ
    https://www.youtube.com/watch?v=dQw4w9WgXcQ
    https://www.youtube.com/watch?v=dQw4w9WgXcQ
    https://www.youtube.com/watch?v=dQw4w9WgXcQ
    https://www.youtube.com/watch?v=dQw4w9WgXcQ
    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
    [BoM.xlsx]
2016-11-18 Everything as it should be... for now
    Connected all subcircuits together as intended (other than solar
    simulator), to verify functionality after adding 100uf caps to both buck
    converters
2016-11-18 Began Board Layout
    Schematic Diagram Done
    Added Database
    (It's a Haiku, as requested)
    [BoM.xlsx]
2016-11-20 All Parts RefDes Updated, 1st Buck Converter Layout
    Added RefDes to components in Library, began actual board layout.
    Currently finished: input filter, MPPT buck converter.
2016-11-23 Board build complete
    I'm not 100% sold on the top copper plane design, currently it is two
    mini-power-planes, but it could have a variety of things. It'll work
    though.
2016-11-28 Fixed indentation and a pointer issue
    Found that indentation in the ADC ISR got screwy.. Fixed that.
    Also realized that I was editing the DCTL variable in a function, but
    hadn't passed it as a pointer.
    [main.c]
2016-11-29 Board Design Finalized
    Silkscreen, copper pours, more jumpers, your mom's house, the whole nine
    yards.
2016-11-29 Updated comments, fixed an issue with DCTL
    Made a bunch of changes to comments with John's changes
    Fixed an issue with the variable type of DCTL
    [main.c]
2016-11-30 Gerber Files
    Get FABulous
    [MQPvGIT - Board Outline.gbr, MQPvGIT - Copper Bottom.gbr, MQPvGIT - Copper Top-Copper Bottom.drl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]
2016-11-30 Axed the logo
    Re-generated the gerbers
    [MQPvGIT - Copper Bottom.gbr, MQPvGIT - Copper Top-Copper Bottom.drl, MQPvGIT - Copper Top.gbr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]
2016-11-30 Mounting Holes because Mechanical Design always comes last
    At least it's not civil.
    [MQPvGIT - Board Outline.gbr, MQPvGIT - Copper Bottom.gbr, MQPvGIT - Copper Top-Copper Bottom.drl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]
2016-12-01 Various code fixes, Flowcharted Main.c
    Reduced the number of global variables in use
    Copied comments from Main.c to Main.h
    Implemented Beta method as per issue #4
    [main.c]
2016-12-01 added mounting, fixed silkscreen
    Fixes #5 and #6.
    [MQPvGIT - Copper Bottom.gbr, MQPvGIT - Copper Top-Copper Bottom.drl, MQPvGIT - Copper Top.gbr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]
2016-12-01 Updated Flow Diagram with additional logic
    Added more of the zero input voltage detection logic.
    Organized flow chart better
2016-12-02 fuck
    fuck fuuck fuck fuck
    [MQPvGIT - Copper Top.gbr, MQPvGIT - Drill Symbols-Copper Top-Copper Bottom.gbr, MQPvGIT - Silkscreen Bottom.gbr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]
2016-12-02 Fixed clearence on VMPPT copper pour
    That is all.
    [MQPvGIT - Copper Top.gbr, MQPvGIT - Drill Symbols-Copper Top-Copper Bottom.gbr]
2016-12-02 version 7 now
    theoretically ready for fab now
    [MQPvGIT - Copper Bottom.gbr, MQPvGIT - Copper Top-Copper Bottom.drl, MQPvGIT - Copper Top.gbr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]
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2016-12-12 added PWM_COMP library
    settings prevented git from recognizing lib file. subckt was pulled out of mppt_models and put into seperate file
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2016-12-13 Replaced tabs with spaces, and fixed comments, etc. to 80 characters
    [main.c]
2016-12-14 BoM Updates for PCB Parts Order
    Hopefully we don't need any more parts.
    [MQPvGIT - Bill of materials.csv, MQPvGIT - Bill of materials.xlsx, MQPvGIT - Digi-Key Cart.csv]
2017-01-23 Made some major changes to Sweep algorithm
    Realized that Sweep algorithm had some glaring issues with how it
    handled the initial sweep.
    Moved zero voltage calculation to MPPT algorithm
    [main.c]
2017-01-26 Cleanup and Exports for Report
    [MQPvGIT.dxf, top_copper.SLDDRW]
2017-01-26 Add functionality for resetting sweep, LED indicates sweep in progress
    [main.c]
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2017-02-06 Fix duty cycle division
    Wasn't resetting MPPT control variable, which was causing it to run far
    faster than it should.
    [main.c]
2017-02-06 Code cleanup, fixed some issues with P&O
    Fixed issue with value of maximum duty cycle
    Added a button with debouncing to change algorithm
    Moved some code out of main into separate functions
    [main.c]
2017-02-08 More code cleanup, not sure why things appeared broken
    Moved some more functionality into a separate function.
    (Should probably make this a statemachine at some point)
    [main.c]
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2017-02-21 Made numerous fixes to Perturb and Observe
    Also commented out Beta algorithm for now
    [main.c]
2017-02-25 Re-wrote loop in main to use statemachines, fixed P&O
    Utilize a state machine for the MPPT tracking and for VOUT
    This improves the readibility immensely and fixes some oddities in the
    behavior.
    [main.c]
2017-02-25 Add support for repeating sweep algorithm at regular interval
    Timer 0 generates input at 16 bit rollover and at LOW_FQ_CLOCK for data
    input. This clock can be used for resetting sweep, or other algorithms
    [main.c]
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2017-03-03 Timer interrupts limited by lowest frequency, fixed issue
    If the timer sets interrupts at 1/5Hz, then can't interrupt more often
    than this, just interrupting at 4KHz and timing off of that, 4KHz*T
    gives count for re-running sweep.
    [main.c]
